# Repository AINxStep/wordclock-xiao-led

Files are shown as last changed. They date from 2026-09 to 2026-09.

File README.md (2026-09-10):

# Reloj de Palabras (WordClock) - Español Mexicano
### Hardware: Seeed Studio XIAO ESP32-C6 + Matriz 158 LEDs WS2812B





🌐 **Idioma / Language:** **Español** | [English](README.en.md)

<p align="center">
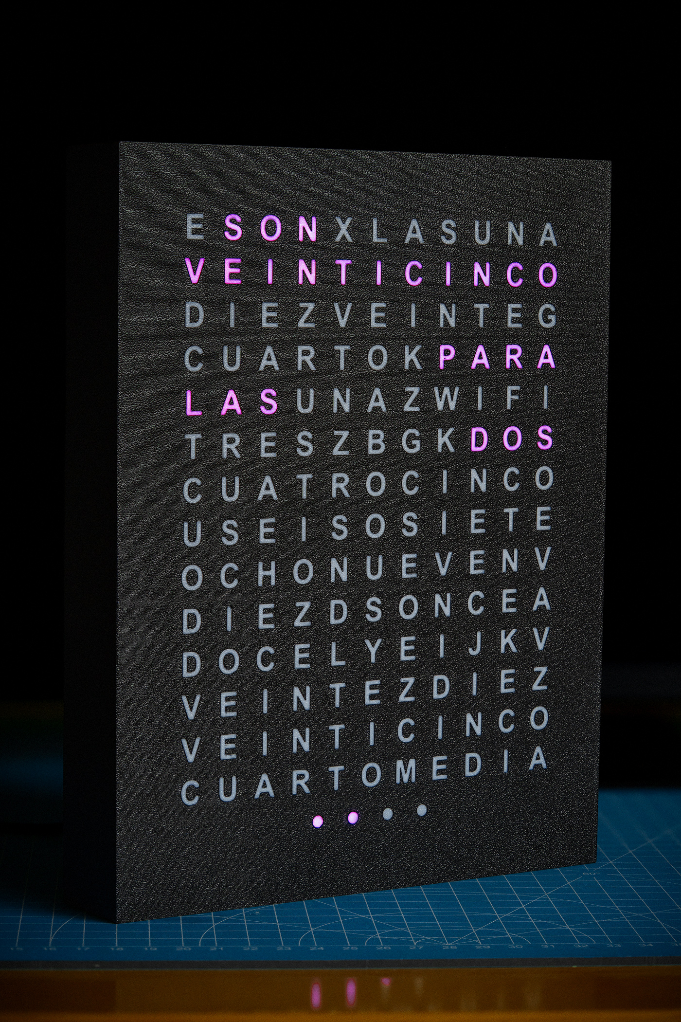
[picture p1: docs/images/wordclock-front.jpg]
Reloj de Palabras - WordClock Español Mexicano
  
  <br>
  <em>WordClock en funcionamiento físico mostrando las 1:37 («SON VEINTICINCO PARA LAS DOS» + 2 minutos)</em>
</p>

---

Proyecto completo de hardware, firmware, modelos 3D y simulador web para un reloj de palabras (*WordClock*) **regionalizado para el español de México** (particularmente el centro del país), con matriz de 158 LEDs direccionables WS2812B y sincronización WiFi / RTC.

---

## 🇲🇽 El Factor Diferenciador: Español Mexicano

La inmensa mayoría de los relojes de palabras en español existentes en internet fueron creados según la convención de España (castellano europeo), la cual utiliza la estructura de resta (*"Las tres menos cuarto"*, *"Las cuatro menos diez"*, *"Las seis menos veinte"*).

En **México**, la manera natural y cotidiana en que decimos la hora invierte la estructura a partir del minuto 35, expresando los minutos que faltan **PARA** la siguiente hora:

* ❌ **Enfoque europeo:** `SON LAS TRES MENOS CUARTO`
* 🇲🇽 **Enfoque mexicano (este WordClock):** `CUARTO PARA LAS TRES`, `DIEZ PARA LAS CUATRO`, `VEINTICINCO PARA LA UNA`

### Adaptación física de la matriz
Para soportar esta sintaxis mexicana de forma natural y visualmente coherente, la matriz de 11×14 se dividió estratégicamente en 3 secciones:

1. **Filas superiores (1 a 4) - Bloque "PARA":** Contienen los minutos preliminares (`VEINTICINCO`, `DIEZ`, `VEINTE`, `CUARTO`), la palabra clave `PARA`, y los artículos `LA` / `LAS` / `UNA` más el indicador de estado `WIFI`.
2. **Filas intermedias (5 a 10) - Bloque de Horas:** Mapean las doce horas (`UNA` a `DOCE`) en orden lógico y optimizado.
3. **Filas inferiores (11 a 13) - Bloque "Y":** Contienen la conjunción `Y` junto con los minutos para la primera mitad de la hora (`DIEZ`, `VEINTE`, `VEINTICINCO`, `CUARTO`, `MEDIA`).
4. **Fila 14 (Puntos de precisión):** 4 LEDs individuales (+1, +2, +3, +4) para lectura exacta minuto a minuto.

---

## Estructura del Repositorio

El repositorio está organizado en módulos independientes para facilitar la navegación y el mantenimiento:

```text
wordclock/
├── docs/                                  # Especificaciones técnicas, esquemas y recursos
│   ├── images/                            # Fotografías y renders del proyecto
│   │   ├── wordclock-front.jpg            # Vista frontal en funcionamiento
│   │   ├── wordclock-internals.jpg        # Ensamble interior y electrónica
│   │   └── wordclock-angle.jpg            # Despiece del ensamble 3D en CAD
│   ├── matrix-layout.txt                  # Mapeo físico detallado de los 158 LEDs (cableado progresivo)
│   └── matrix-grid.txt                    # Distribución de la cuadrícula de texto (11x14)
│
├── simulator/                             # Simulador Web interactivo
│   ├── index.html                         # Interfaz gráfica del simulador
│   ├── index.css                          # Estilos visuales y efectos de iluminación LED
│   └── app.js                             # Lógica de tiempo en español mexicano y portal WiFi
│
├── arduino/                               # Firmware para Arduino IDE
│   ├── wordclock/                         # Sketch principal
│   │   └── wordclock.ino                  # Firmware completo (ESP32-C6 + FastLED + RTC DS1307 + AP Portal)
│   ├── test_words/                        # Sketch de diagnóstico y pruebas
│   │   └── test_words.ino                 # Prueba secuencial de palabras e iluminación
│   └── reference/                         # Códigos de referencia y ejemplos base
│       └── wordclock-example.code.txt
│
├── 3d_models/                             # Archivos de impresión 3D (OpenSCAD, STL, 3MF)
│   ├── best_parameters.txt                # Parámetros recomendados de laminación (Bambu Studio)
│   ├── opcion_1_tapa_superpuesta/         # Opción 1: Tapa exterior superpuesta para marco estándar
│   └── opcion_2_tapa_incrustada_al_ras/   # Opción 2: Tapa incrustada al ras para marco optimizado
│
└── LICENSE                                # Licencia dual (MIT para software, CC BY-SA 4.0 para hardware/3D)
```

---

## Hardware y Lista de Materiales (BOM)

* **Placa Base / Driver**: [Seeed LED Driver Board](https://wiki.seeedstudio.com/led_driver_board/) (Alimentación única 12V DC, regulador interno, zócalo integrado para XIAO, puerto Grove I2C y salida directa para tira LED)
* **Microcontrolador**: [Seeed Studio XIAO ESP32-C6](https://wiki.seeedstudio.com/xiao_esp32c6_getting_started/) (montado directamente en el zócalo de la placa driver)
* **Módulo RTC**: [Grove - DS1307 RTC](https://wiki.seeedstudio.com/Grove-RTC/#pre-reading) (conectado con cable Grove nativo al puerto I2C de la placa driver)
* **Tira de LEDs**: WS2812B de 74 LEDs/m (158 LEDs en total: matriz 11×14 + 4 puntos de minutos)
* **Conector de Chasis**: [Puerto USB-C Hembra impermeable para panel (2 pines, 3A)](https://es.aliexpress.com/item/1005011950115260.html) con cable de extensión hacia la placa driver
* **Alimentación**: [Adaptador de Corriente Universal USB-C 24W (12V @ 2A)](https://es.aliexpress.com/item/1005007438665930.html)

<p align="center">
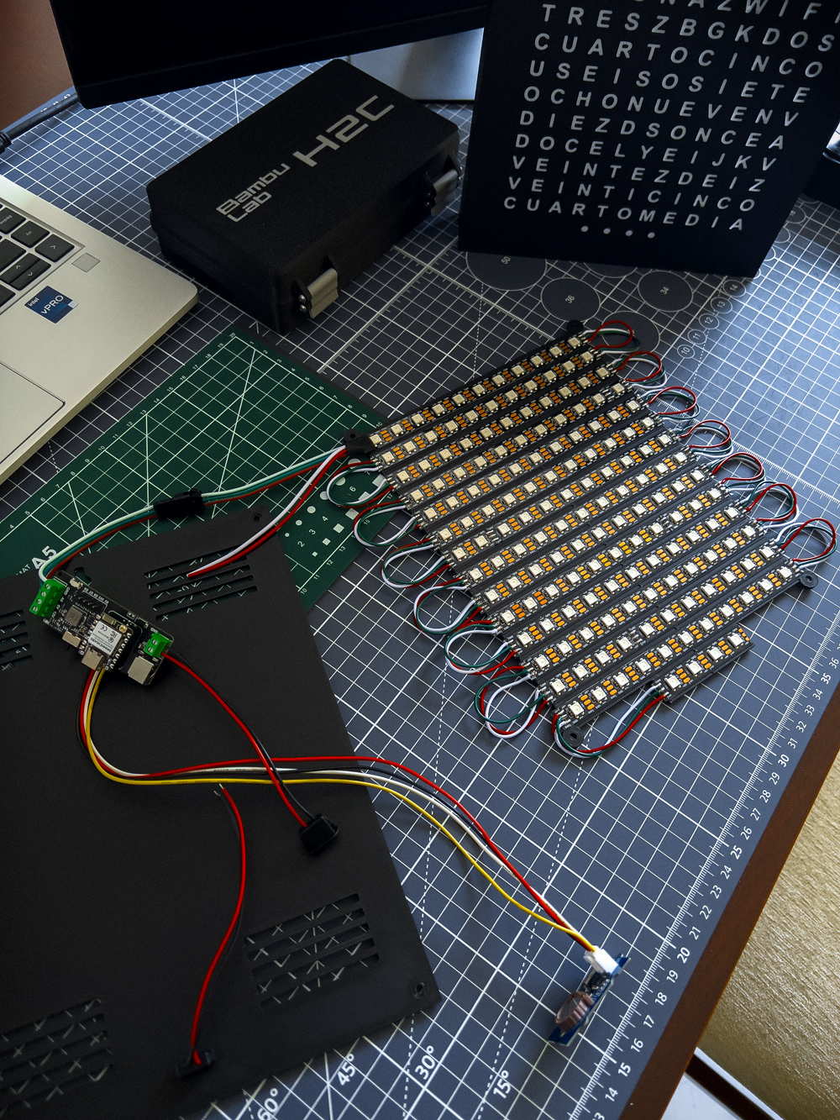
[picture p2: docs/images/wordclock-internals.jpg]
Ensamble interno y componentes de WordClock
  
  <br>
  <em>Componentes y cableado interno: Placa Seeed LED Driver con XIAO ESP32-C6, módulo Grove RTC (DS1307), placa posterior con ventilación y matriz de tiras LED WS2812B interconectadas</em>
</p>

### Diagrama de Conexiones

```mermaid
flowchart TD
    subgraph PWR["Alimentación Externa y Chasis"]
        V12["Adaptador USB-C 12V / 2A (24W)"]
        USBC_PORT["Puerto USB-C Hembra Impermeable (Panel Trasero)"]
    end

    subgraph DriverBoard["Seeed Studio LED Driver Board (Placa Base)"]
        DC_IN["Entrada de Alimentación: 12V DC"]
        REG["Regulación interna DC-DC (12V → 5V / 3.3V) + Level Shifter"]

        subgraph XiaoSocket["Zócalo XIAO"]
            XIAO["Seeed Studio XIAO ESP32-C6<br>(Montado directamente en zócalo)"]
        end

        subgraph GrovePort["Puerto Grove I2C"]
            GROVE_OUT["SCL / SDA / VCC / GND"]
        end

        subgraph LedOut["Conector de Salida para Tira LED"]
            OUT_GND["GND"]
            OUT_DAT["DATA (5V Level-Shifted)"]
            OUT_5V["+5V"]
            OUT_12V["+12V (No utilizado)"]
        end
    end

    subgraph RTC["Grove RTC (DS1307)"]
        RTC_PORT["Puerto Grove I2C<br>(SCL, SDA, VCC, GND)"]
    end

    subgraph Matriz["Matriz LEDs WS2812B (158 LEDs)"]
        LED_DIN["DIN (LED #0)"]
        LED_VCC["+5V"]
        LED_GND["GND"]
    end

    V12 --> USBC_PORT
    USBC_PORT --> DC_IN
    DC_IN --> REG
    REG --> XIAO
    REG --> GrovePort
    REG --> LedOut

    GrovePort <== Cable Grove (I2C + Energía) ==> RTC_PORT

    OUT_DAT --> LED_DIN
    OUT_5V --> LED_VCC
    OUT_GND --> LED_GND
```

### Tabla de Cableado

| Conector / Puerto | Pines / Terminales | Componente Conectado | Función / Descripción |
| :--- | :--- | :--- | :--- |
| **Panel Trasero (Chasis)** | `VBUS (12V)`, `GND` | [Puerto USB-C Hembra Impermeable](https://es.aliexpress.com/item/1005011950115260.html) | Entrada externa en el chasis para recibir alimentación mediante cable USB-C |
| **Entrada DC Driver** | `12V`, `GND` | [Adaptador USB-C 12V @ 2A](https://es.aliexpress.com/item/1005007438665930.html) | Fuente conmutada regulada de 24W que alimenta todo el sistema |
| **Zócalo XIAO** | Headers hembra | [XIAO ESP32-C6](https://wiki.seeedstudio.com/xiao_esp32c6_getting_started/) | Interconexión directa de energía, bus I2C y pin de señal `D0/GPIO 0` |
| **Puerto Grove I2C** | `SCL`, `SDA`, `VCC`, `GND` | [Grove RTC (DS1307)](https://wiki.seeedstudio.com/Grove-RTC/#pre-reading) | Conexión directa mediante cable Grove estándar (datos I2C + energía) |
| **Conector Salida LED**| `DATA`, `+5V`, `GND` | Matriz WS2812B (158 LEDs) | Salida regulada a 5V y señal digital para el primer LED (`DIN`) |

> [!TIP]
> **Alimentación del sistema**: El reloj requiere únicamente un adaptador externo de **12V @ 2A**. La placa Seeed LED Driver Board se encarga internamente de convertir y distribuir los voltajes requeridos: 3.3V para el microcontrolador XIAO, 5V para el módulo Grove RTC y 5V con suficiente corriente para alimentar los 158 LEDs WS2812B.

---

## Matriz de Letras (11×14 + 4 Puntos)

```text
Fila 0  (0-10):    E S O N X L A S U N A    (ES, SON, LA, LAS, UNA)
Fila 1  (11-21):   V E I N T I C I N C O    (Minutos para bloque PARA)
Fila 2  (22-32):   D I E Z V E I N T E G    (Minutos para bloque PARA)
Fila 3  (33-43):   C U A R T O K P A R A    (CUARTO, PARA)
Fila 4  (44-54):   L A S U N A Z W I F I    (LA, LAS, UNA para bloque PARA + WIFI)
Fila 5  (55-65):   T R E S Z B G K D O S    (Horas: TRES, DOS)
Fila 6  (66-76):   C U A T R O C I N C O    (Horas: CUATRO, CINCO)
Fila 7  (77-87):   U S E I S O S I E T E    (Horas: SEIS, SIETE)
Fila 8  (88-98):   O C H O N U E V E N V    (Horas: OCHO, NUEVE)
Fila 9  (99-109):  D I E Z D S O N C E A    (Horas: DIEZ, ONCE)
Fila 10 (110-120): D O C E L Y E I J K V    (Horas: DOCE, Conjunción Y)
Fila 11 (121-131): V E I N T E Z D I E Z    (Minutos para bloque Y)
Fila 12 (132-142): V E I N T I C I N C O    (Minutos para bloque Y)
Fila 13 (143-153): C U A R T O M E D I A    (Minutos para bloque Y)
Fila 14 (154-157): Puntos de minutos (+1, +2, +3, +4)
```

* **Bloque "Y"** (minutos 00 a 34): *Ej. "SON LAS ONCE Y VEINTE"*, *"ES LA UNA Y DIEZ"*
* **Bloque "PARA"** (minutos 35 a 59): *Ej. "VEINTICINCO PARA LAS DOCE"*, *"CUARTO PARA LA UNA"*
* **Puntos de minutos (+1 a +4)**: Ajuste exacto de minutos individuales.

---

## Cómo Usar

### 1. Simulador Web
* **🌐 Probar en línea (sin descargas)**: Accede a la demo en vivo directamente en [ainxstep.github.io/wordclock-xiao-led](https://ainxstep.github.io/wordclock-xiao-led/).
* **💻 Ejecución local**: Abre directamente `simulator/index.html` en cualquier navegador web moderno para verificar la lógica de iluminación en español mexicano, ajustar la hora manualmente con el slider o sincronizarla en tiempo real.

### 2. Firmware (Arduino IDE)
1. Instala la placa **ESP32 by Espressif Systems** en el Gestor de Placas de Arduino IDE.
2. Instala las librerías necesarias: `FastLED` y `RTClib` (Adafruit).
3. Abre el sketch `arduino/wordclock/wordclock.ino`.
4. Selecciona la placa **Seeed Studio XIAO ESP32C6** y el puerto correspondiente.
5. Compila y carga el código.

### 3. Impresión 3D y Ensamble

<p align="center">
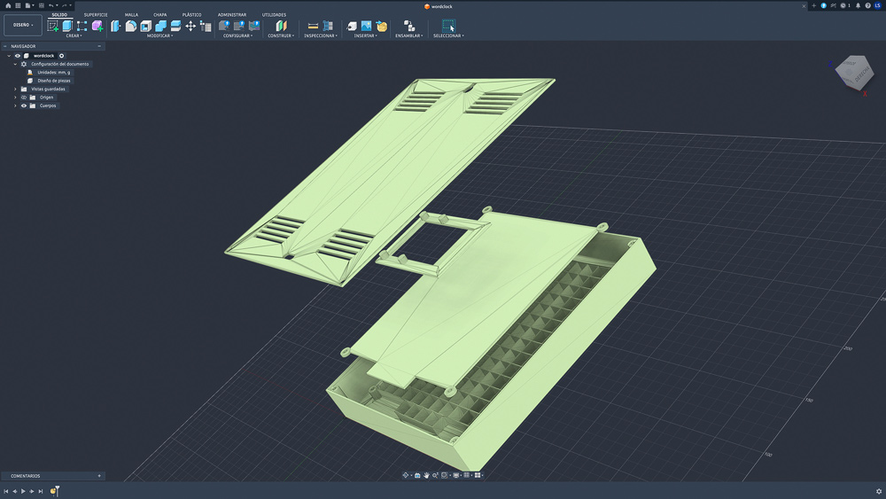
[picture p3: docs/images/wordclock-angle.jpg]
Despiece y ensamble 3D de WordClock
  
  <br>
  <em>Despiece del ensamble 3D: Marco frontal con rejilla de aislamiento óptico, placa porta-LEDs, soporte de electrónica y tapa trasera ventilada</em>
</p>

Dentro de `3d_models/` se encuentran los modelos paramétricos en OpenSCAD y los archivos `.stl` / `.3mf` listos para laminar:
* **Marco principal (`wordclock_main_frame`)**: Frontal con celdas individuales para cada letra y punto de minuto, diseñadas para aislar completamente la luz de cada LED (*anti-light-bleed*).
* **Placa de LEDs (`wordclock_led_plate`)**: Base con ranuras y marcas para el pegado y alineación milimétrica de las tiras WS2812B.
* **Soporte de electrónica (`wordclock_electronics_mount`)**: Base adaptada para fijar con tornillos la placa Seeed LED Driver y el módulo RTC.
* **Tapa trasera (`wordclock_back_lid`)**: Disponible en dos opciones: **Opción 1** (tapa superpuesta estándar) y **Opción 2** (tapa incrustada al ras), ambas con ranuras para ventilación pasiva.

Consulta `3d_models/best_parameters.txt` para los ajustes de capa, ancho de línea y patrones de relleno recomendados en Bambu Studio.

> [!TIP]
> **Proyecto listo para Bambu Studio**: Si utilizas una impresora Bambu Lab (o Bambu Studio / OrcaSlicer), puedes abrir directamente el archivo de proyecto preconfigurado [`3d_models/opcion_2_tapa_incrustada_al_ras/wordclock.3mf`](3d_models/opcion_2_tapa_incrustada_al_ras/wordclock.3mf). Contiene las bandejas organizadas, orientaciones óptimas de piezas, asignación de filamentos y parámetros de laminación listos para imprimir con un clic.

### 4. Configuración Inicial y Portal WiFi

Al conectar el reloj a la alimentación USB, la palabra **WIFI** pulsa suavemente durante los primeros **60 segundos**, indicando que la red de configuración está activa y lista para recibir conexiones.

1. **Conéctate a la red**: Desde tu teléfono o computadora, conéctate a la red WiFi **`WORDCLOCK-SETUP`** (red abierta, sin contraseña).
2. **Accede al portal**: Se abrirá automáticamente la ventana del portal cautivo. Si no aparece sola, entra desde el navegador a `http://192.168.4.1`.
3. **Ajusta tus preferencias**:
   * **Sincronizar hora**: Presiona el botón para transferir al instante la hora y fecha exacta de tu teléfono al chip RTC (Grove DS1307).
   * **Color y brillo**: Elige el color de las palabras y gradúa el brillo diurno y nocturno (optimizado con corrección Gamma 2.2).
   * **Horario nocturno**: Define el intervalo de horas para el modo tenue (ej. 22:00 a 06:00).
4. **Guarda**: Presiona **"Guardar Configuración"**. Los ajustes se aplican de inmediato y se almacenan en la memoria permanente (NVS) del ESP32.

> [!NOTE]
> **Modo normal y reconfiguración**: Si pasan 60 segundos sin conexión o en cuanto te desconectas del portal, la antena WiFi y la palabra **WIFI** se apagan por completo para no emitir radiofrecuencia. Para volver a abrir el portal de configuración en el futuro, simplemente **desconecta y vuelve a conectar el cable de alimentación USB**.

---

## Licencia

Este proyecto cuenta con un esquema de licenciamiento dual:
* **Software y Firmware (`arduino/`, `simulator/`)**: Licencia [MIT](LICENSE).
* **Modelos 3D, Hardware y Documentación (`3d_models/`, `docs/`)**: Licencia [Creative Commons Atribución-CompartirIgual 4.0 Internacional (CC BY-SA 4.0)](LICENSE).

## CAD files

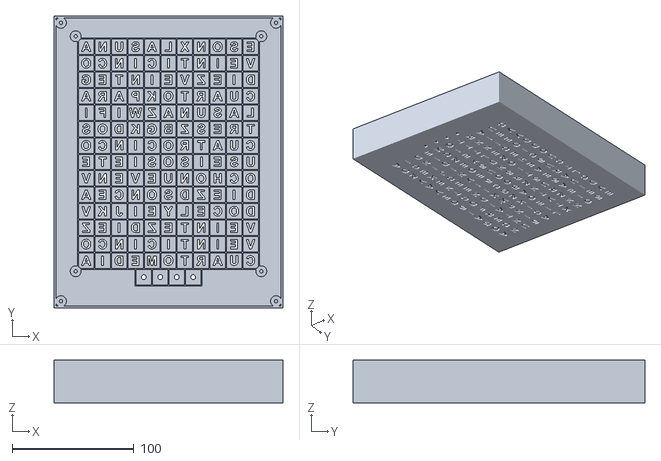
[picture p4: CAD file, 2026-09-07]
3d_models/opcion_2_tapa_incrustada_al_ras/wordclock_main_frame.stl
188.0 x 240.0 x 35.0

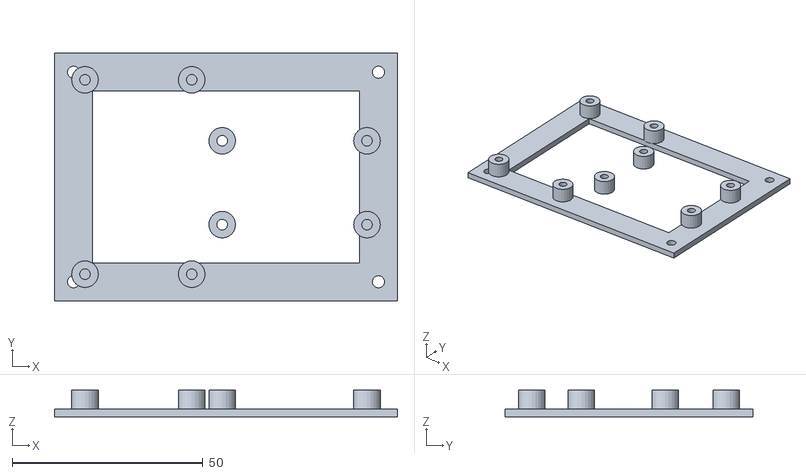
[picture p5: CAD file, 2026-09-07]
3d_models/opcion_1_tapa_superpuesta/wordclock_electronics_mount.stl
90.0 x 65.0 x 7.00

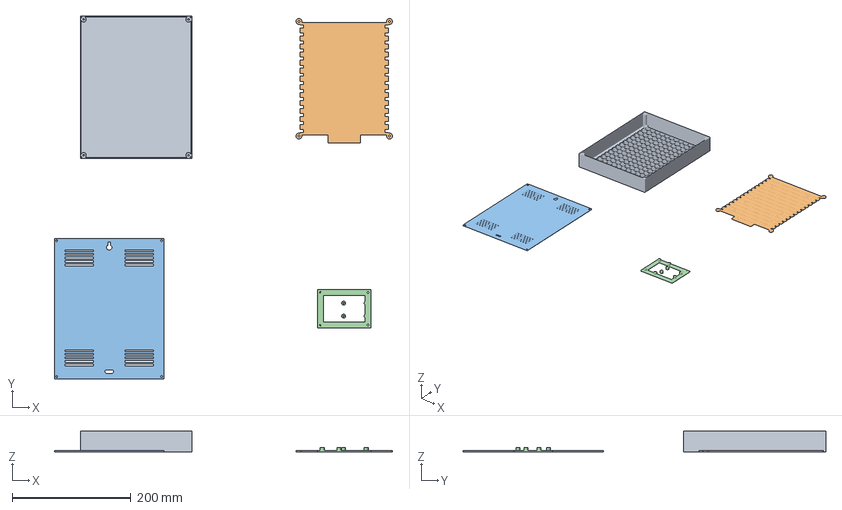
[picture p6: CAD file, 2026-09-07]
3d_models/opcion_2_tapa_incrustada_al_ras/wordclock.3mf
569.5 x 611.3 x 35.0 mm
wordclock_letters_infill
wordclock_led_plate.stl
wordclock_back_lid.stl
wordclock_electronics_mount.stl

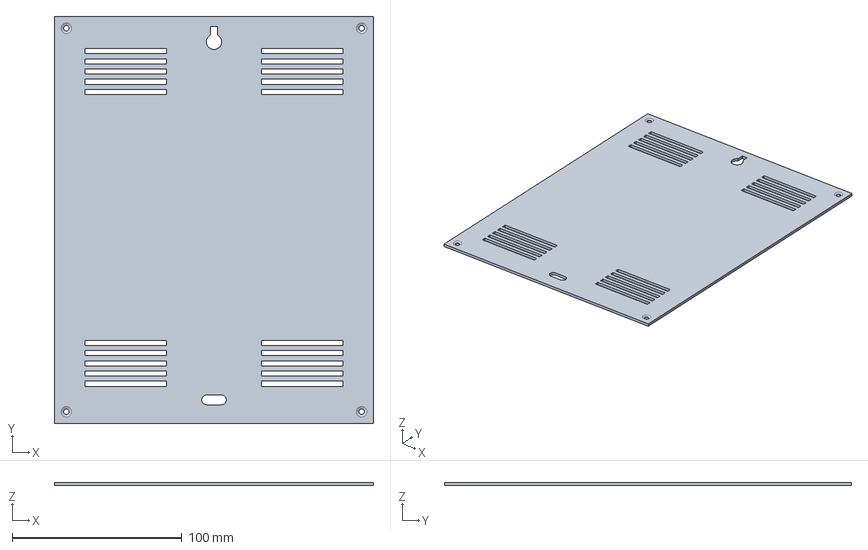
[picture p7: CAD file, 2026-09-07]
3d_models/opcion_1_tapa_superpuesta/wordclock_back_lid.3mf
188.0 x 240.0 x 2.00 mm

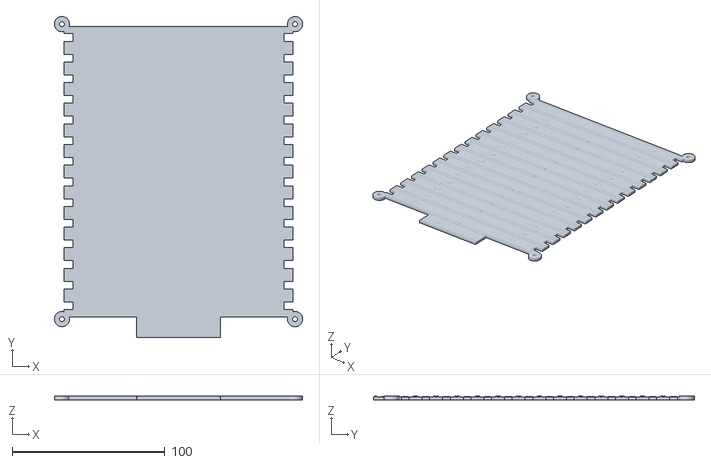
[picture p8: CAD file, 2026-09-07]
3d_models/opcion_2_tapa_incrustada_al_ras/wordclock_led_plate.stl
162.6 x 210.2 x 2.40

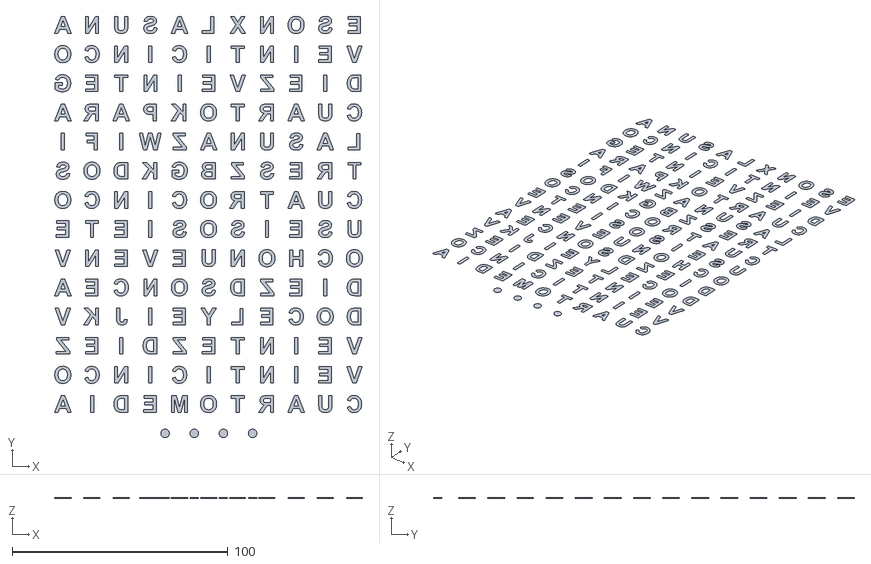
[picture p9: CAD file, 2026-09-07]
3d_models/opcion_1_tapa_superpuesta/wordclock_letters_infill.stl
142.7 x 195.3 x 0.4

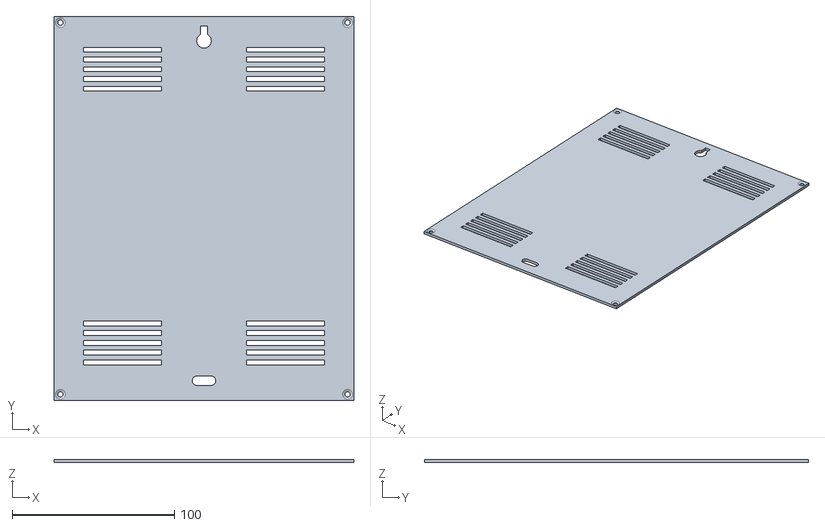
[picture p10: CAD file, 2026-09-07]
3d_models/opcion_2_tapa_incrustada_al_ras/wordclock_back_lid.stl
184.4 x 236.4 x 2.00

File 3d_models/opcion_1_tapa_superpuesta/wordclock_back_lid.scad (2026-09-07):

// ==============================================================================
// WORDCLOCK ESP32 - OPCION 1: TAPA TRASERA SUPERPUESTA (PARA MARCO YA IMPRESO)
// PIEZA 3: TAPA SUPERPUESTA DE 188.0 x 240.0 mm
// Offset de tornillos: 7.0 mm (Coincide EXACTAMENTE con la impresión física realizada)
// Avellanado simétrico (doble cara) para que la cabeza del tornillo encaje sin importar el lado
// ==============================================================================

box_w       = 188.0;   // Ancho exterior completo (188 mm)
box_h       = 240.0;   // Alto exterior completo (240 mm)
wall_thick  = 3.0;     // Pared de 3.0 mm coincidente con el marco impreso
lid_thick   = 2.0;     // Grosor de la tapa

// Centro de tornillos a 7.0 mm desde las esquinas exteriores
screw_off   = wall_thick + 4.0; // 3.0 + 4.0 = 7.0 mm

module double_countersunk_hole(h = 2.0) {
    union() {
        // Pasante central M3
        translate([0, 0, -0.1]) cylinder(r = 1.6, h = h + 0.2, $fn = 32);
        
        // Avellanado Cara A (Cono de 1.6 mm a 3.3 mm en los primeros 0.9 mm)
        translate([0, 0, -0.1]) cylinder(r1 = 3.3, r2 = 1.6, h = 0.9, $fn = 32);
        
        // Avellanado Cara B (Cono de 1.6 mm a 3.3 mm en los últimos 0.9 mm)
        translate([0, 0, h - 0.8]) cylinder(r1 = 1.6, r2 = 3.3, h = 0.9, $fn = 32);
    }
}

module wordclock_back_lid() {
    difference() {
        // 1. Placa Base de la Tapa (188.0 x 240.0 x 2.0 mm)
        cube([box_w, box_h, lid_thick]);

        // 2. Orificios M3 con Avellanado Doble Cara (Offset exacto 7.0 mm)
        translate([screw_off, screw_off, 0])                 double_countersunk_hole(lid_thick);
        translate([box_w - screw_off, screw_off, 0])         double_countersunk_hole(lid_thick);
        translate([screw_off, box_h - screw_off, 0])         double_countersunk_hole(lid_thick);
        translate([box_w - screw_off, box_h - screw_off, 0]) double_countersunk_hole(lid_thick);

        // 3. Ranuras de Ventilación Superior
        for (i = [0 : 4]) {
            y_slot = box_h - 22 - (i * 6);
            translate([18, y_slot, -0.1])         cube([48, 3.0, lid_thick + 0.2]);
            translate([box_w - 66, y_slot, -0.1]) cube([48, 3.0, lid_thick + 0.2]);
        }

        // 4. Ranuras de Ventilación Inferior
        for (i = [0 : 4]) {
            y_slot = 22 + (i * 6);
            translate([18, y_slot, -0.1])         cube([48, 3.0, lid_thick + 0.2]);
            translate([box_w - 66, y_slot, -0.1]) cube([48, 3.0, lid_thick + 0.2]);
        }

        // 5. RANURA USB-C OBLONGA / PANELSOCKET (14.5 x 5.8 mm con r = 2.9 mm)
        translate([box_w / 2, 14.0, -0.1]) {
            hull() {
                translate([-4.35, 0, 0]) cylinder(r = 2.9, h = lid_thick + 0.2, $fn = 32);
                translate([ 4.35, 0, 0]) cylinder(r = 2.9, h = lid_thick + 0.2, $fn = 32);
            }
        }

        // 6. Muesca de cerradura (Keyhole) para colgar en pared
        translate([box_w / 2, box_h - 15, -0.1]) {
            union() {
                cylinder(r = 4.5, h = lid_thick + 0.2, $fn = 24);
                translate([-2.2, 0, 0]) cube([4.4, 9.0, lid_thick + 0.2]);
            }
        }
    }
}

wordclock_back_lid();

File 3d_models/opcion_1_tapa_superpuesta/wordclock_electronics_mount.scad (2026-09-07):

// ==============================================================================
// WORDCLOCK ESP32 - OPCION 1: SOPORTE DE ELECTRONICA INDEPENDIENTE
// PIEZA 4: BANDEJA DE MONTAJE PARA ESP32 + MODULO RTC DS1307
// ==============================================================================

tray_w     = 90.0;
tray_h     = 65.0;
tray_thick = 2.0;
standoff_h = 5.0;

module m3_boss(h = 5.0) {
    difference() {
        cylinder(r = 3.5, h = h, $fn = 24);
        translate([0, 0, -0.1]) cylinder(r = 1.4, h = h + 0.2, $fn = 24);
    }
}

module wordclock_electronics_mount() {
    union() {
        difference() {
            cube([tray_w, tray_h, tray_thick]);

            translate([10, 10, -0.1]) {
                cube([tray_w - 20, tray_h - 20, tray_thick + 0.2]);
            }

            translate([5, 5, -0.1])           cylinder(r = 1.6, h = tray_thick + 0.2, $fn = 24);
            translate([tray_w - 5, 5, -0.1])   cylinder(r = 1.6, h = tray_thick + 0.2, $fn = 24);
            translate([5, tray_h - 5, -0.1])  cylinder(r = 1.6, h = tray_thick + 0.2, $fn = 24);
            translate([tray_w - 5, tray_h - 5, -0.1]) cylinder(r = 1.6, h = tray_thick + 0.2, $fn = 24);
        }

        esp32_x = 8;
        esp32_y = 7;
        translate([esp32_x, esp32_y, tray_thick]) {
            m3_boss(standoff_h);
            translate([28, 0, 0])  m3_boss(standoff_h);
            translate([0, 51, 0])  m3_boss(standoff_h);
            translate([28, 51, 0]) m3_boss(standoff_h);
        }

        rtc_x = 44;
        rtc_y = 20;
        translate([rtc_x, rtc_y, tray_thick]) {
            m3_boss(standoff_h);
            translate([38, 0, 0])  m3_boss(standoff_h);
            translate([0, 22, 0])  m3_boss(standoff_h);
            translate([38, 22, 0]) m3_boss(standoff_h);
        }
    }
}

wordclock_electronics_mount();

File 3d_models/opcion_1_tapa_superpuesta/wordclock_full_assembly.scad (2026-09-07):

// ==============================================================================
// WORDCLOCK ESP32 - OPCION 1: VISTA GENERAL DE ENSAMBLAJE & EXPLOSIONADA (EXPLODED VIEW)
// Modelo concentrado para auditoría 3D de ajuste entre piezas (Marco 3.0 mm + Tapa 188x240 mm)
// ==============================================================================

/* [Controles de Vista e Inspección / View Controls] */
// Desplazamiento de explosión en mm (0 = 100% Ensamblado Real, >0 = Vista Despiezada/Explosionada)
explode_distance = 0; // [0:1:120]

// Modo Transparencia para inspeccionar interferencias internas y alineación de tornillos
transparent_view = 0; // [0:Sólido, 1:Transparente]

// Visibilidad de Piezas Individuales
show_main_frame       = 1; // [0:Ocultar, 1:Mostrar]
show_led_plate        = 1; // [0:Ocultar, 1:Mostrar]
show_electronics_mount= 1; // [0:Ocultar, 1:Mostrar]
show_back_lid         = 1; // [0:Ocultar, 1:Mostrar]

// Incluir definidores de módulos de las 4 piezas
include <wordclock_main_frame.scad>
include <wordclock_back_lid.scad>

// --- Definición abreviada de la Placa de LEDs (Pieza 2) ---
module led_plate_component() {
    grid_w      = (11 - 1) * 13.5135;
    grid_h      = (14 - 1) * 13.5135;
    margin_x    = (188.0 - grid_w) / 2;
    margin_top  = (240.0 - grid_h - 13.5135) / 2;
    dots_y      = 240.0 - margin_top - (14 * 13.5135);
    
    plate_left  = margin_x - (13.5135 / 2) - 0.5;
    plate_right = margin_x + grid_w + (13.5135 / 2) + 0.5;
    plate_top   = 240.0 - margin_top + (13.5135 / 2) + 0.5;
    plate_bot   = 240.0 - margin_top - grid_h - (13.5135 / 2) - 0.5;
    plate_w     = plate_right - plate_left;
    plate_h     = plate_top - plate_bot;
    
    baffle_left  = margin_x - (13.5135 / 2) - 2.0;
    baffle_right = margin_x + grid_w + (13.5135 / 2) + 2.0;
    baffle_top   = 240.0 - margin_top + (13.5135 / 2) + 2.0;
    baffle_bot   = 240.0 - margin_top - grid_h - (13.5135 / 2) - 2.0;
    
    difference() {
        union() {
            translate([plate_left, plate_bot, 0]) cube([plate_w, plate_h, 2.0]);
            dots_plate_w = (4 * 13.5135) + 0.8;
            dots_plate_x = margin_x + (3.0 * 13.5135) - 0.4;
            dots_plate_y = dots_y - (13.5135 / 2) - 0.5;
            dots_plate_h = (plate_bot - dots_plate_y) + 1.0;
            translate([dots_plate_x, dots_plate_y, 0]) cube([dots_plate_w, dots_plate_h, 2.0]);
            
            // 4 Orejas de fijación
            translate([baffle_left, baffle_top, 0])   cylinder(r = 5.0, h = 2.4, $fn = 32);
            translate([baffle_right, baffle_top, 0])  cylinder(r = 5.0, h = 2.4, $fn = 32);
            translate([baffle_left, baffle_bot, 0])   cylinder(r = 5.0, h = 2.4, $fn = 32);
            translate([baffle_right, baffle_bot, 0])  cylinder(r = 5.0, h = 2.4, $fn = 32);
        }
        // Pasantes M3 en las 4 orejas
        translate([baffle_left, baffle_top, -0.1])   cylinder(r = 1.6, h = 3.0, $fn = 32);
        translate([baffle_right, baffle_top, -0.1])  cylinder(r = 1.6, h = 3.0, $fn = 32);
        translate([baffle_left, baffle_bot, -0.1])   cylinder(r = 1.6, h = 3.0, $fn = 32);
        translate([baffle_right, baffle_bot, -0.1])  cylinder(r = 1.6, h = 3.0, $fn = 32);
    }
}

// --- Definición abreviada del Soporte de Electrónica (Pieza 4) ---
module electronics_mount_component() {
    difference() {
        cube([90.0, 65.0, 2.0]);
        translate([10, 10, -0.1]) cube([70.0, 45.0, 2.2]);
        translate([5, 5, -0.1])           cylinder(r = 1.6, h = 2.2, $fn = 24);
        translate([85, 5, -0.1])          cylinder(r = 1.6, h = 2.2, $fn = 24);
        translate([5, 60, -0.1])          cylinder(r = 1.6, h = 2.2, $fn = 24);
        translate([85, 60, -0.1])         cylinder(r = 1.6, h = 2.2, $fn = 24);
    }
    // Torretas M3 para ESP32
    translate([8, 7, 2.0]) {
        cylinder(r = 3.5, h = 5.0, $fn = 24);
        translate([28, 0, 0])  cylinder(r = 3.5, h = 5.0, $fn = 24);
        translate([0, 51, 0])  cylinder(r = 3.5, h = 5.0, $fn = 24);
        translate([28, 51, 0]) cylinder(r = 3.5, h = 5.0, $fn = 24);
    }
}

// --- RENDERING DEL ENSAMBLAJE TOTAL ---
alpha_val = (transparent_view == 1) ? 0.45 : 1.0;

module full_wordclock_assembly() {
    // 1. Pieza 1: Marco Principal (Z = 0)
    if (show_main_frame == 1) {
        color([0.22, 0.22, 0.22, alpha_val]) {
            wordclock_main_frame();
        }
    }

    // 2. Pieza 2: Placa Porta-LEDs (Apoyada a Z = face_thick + baffle_h = 14.4 mm)
    if (show_led_plate == 1) {
        translate([0, 0, 14.4 + (explode_distance * 0.5)]) {
            color([0.9, 0.9, 0.9, alpha_val]) {
                led_plate_component();
            }
        }
    }

    // 3. Pieza 4: Soporte de Electrónica (Centrado a Z = 22.0 mm)
    if (show_electronics_mount == 1) {
        translate([49.0, 87.5, 20.0 + (explode_distance * 1.1)]) {
            color([0.1, 0.6, 0.8, alpha_val]) {
                electronics_mount_component();
            }
        }
    }

    // 4. Pieza 3: Tapa Trasera (Montada a Z = 35.0 mm por fuera)
    if (show_back_lid == 1) {
        translate([0, 0, 35.0 + (explode_distance * 1.8)]) {
            color([0.85, 0.55, 0.2, alpha_val]) {
                wordclock_back_lid();
            }
        }
    }
}

// Renderizar ensamblaje completo con la distancia de explosión seleccionada
full_wordclock_assembly();

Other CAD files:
3d_models/opcion_2_tapa_incrustada_al_ras/wordclock_letters_infill.stl
3d_models/opcion_1_tapa_superpuesta/wordclock_led_plate.stl
3d_models/opcion_2_tapa_incrustada_al_ras/wordclock_electronics_mount.stl
3d_models/opcion_1_tapa_superpuesta/wordclock_led_plate.scad
3d_models/opcion_1_tapa_superpuesta/wordclock_back_lid.stl
3d_models/opcion_1_tapa_superpuesta/wordclock_letters_infill.scad
3d_models/opcion_1_tapa_superpuesta/wordclock_main_frame.scad
3d_models/opcion_2_tapa_incrustada_al_ras/wordclock_back_lid.scad
3d_models/opcion_2_tapa_incrustada_al_ras/wordclock_electronics_mount.scad
3d_models/opcion_2_tapa_incrustada_al_ras/wordclock_full_assembly.scad
3d_models/opcion_2_tapa_incrustada_al_ras/wordclock_led_plate.scad
3d_models/opcion_2_tapa_incrustada_al_ras/wordclock_letters_infill.scad
3d_models/opcion_2_tapa_incrustada_al_ras/wordclock_main_frame.scad

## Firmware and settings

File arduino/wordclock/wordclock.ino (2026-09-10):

/*
  Reloj de Palabras (WordClock Seeed Studio XIAO ESP32-C6)
  Hardware: Microcontrolador Seeed Studio XIAO ESP32-C6 + Seeed LED Driver Board + Grove RTC (DS1307)
  Matriz: 11x14 + 4 puntos de minutos (158 LEDs totales, WS2812B 74 LEDs/m)
  Pin de datos LED: D0 / A0 (GPIO 0) mediante Seeed LED Driver Board (Level Shifter 3.3V -> 5V)
  Bus I2C RTC: Puerto Grove I2C nativo (SDA/SCL a 100 kHz para módulo Grove DS1307)
  LED Integrado XIAO: GPIO 15 (Parpadeo durante modo WiFi AP activo)
  Indicador WiFi: índices 51-54 ("WIFI" en Fila 4)
  Configuración: Captive Portal WebServer idéntico al simulador en AP "WORDCLOCK-SETUP"
*/

#include <FastLED.h>
#include <Wire.h>
#include <RTClib.h>

#include <WiFi.h>
#include <WebServer.h>
#include <DNSServer.h>
#include <Preferences.h>
#include <time.h>

/* ========== Configuración Hardware Seeed Studio XIAO ESP32-C6 ========== */
#define DATA_PIN 0            // Pin D0 (GPIO 0) en XIAO ESP32-C6 (Entrada al Level Shifter del LED Driver Board)
#define LED_PIN_BUILTIN 15    // Pin LED Integrado en XIAO ESP32-C6 (Lógica Invertida: LOW = ON, HIGH = OFF)
#define NUM_LEDS 158

// Velocidad I2C Estándar para DS1307 (100 kHz)
#define I2C_SPEED_DS1307 100000UL

// Instancia del RTC Grove basado en chip DS1307
RTC_DS1307 rtc;

CRGB leds[NUM_LEDS];
CRGB targetLeds[NUM_LEDS];

WebServer server(80);
DNSServer dnsServer;
Preferences prefs;

const byte DNS_PORT = 53;

/* ========== Valores por Defecto ========== */
const uint8_t DEFAULT_DAY_BRI_PERCENT = 70;
const uint8_t DEFAULT_NIGHT_BRI_PERCENT = 20;
const uint8_t DEFAULT_NIGHT_START = 22;
const uint8_t DEFAULT_NIGHT_END = 6;
const CRGB DEFAULT_COLOR = CRGB(255, 140, 0); // Ámbar por defecto (#ff8c00)

/* ========== Configuración en Tiempo de Ejecución ========== */
uint8_t dayBrightPercent = DEFAULT_DAY_BRI_PERCENT;
uint8_t nightBrightPercent = DEFAULT_NIGHT_BRI_PERCENT;
uint8_t nightStartHour = DEFAULT_NIGHT_START;
uint8_t nightEndHour = DEFAULT_NIGHT_END;
CRGB WORD_COLOR = DEFAULT_COLOR;

/* Claves para Preferences (memoria no volátil) */
const char *P_NS = "nightStart";
const char *P_NE = "nightEnd";
const char *P_DB = "dayB";
const char *P_NB = "nightB";
const char *P_R = "rc";
const char *P_G = "gc";
const char *P_B = "bc";

/* ========== Corrección Gamma 2.2 y Modelado Perceptual Humano ========== */
// Mapea porcentajes/valores lineales (0-255) a emisión óptica percibida como lineal (Ley de Stevens)
const uint8_t PROGMEM GAMMA8[256] = {
    0,   1,   1,   1,   1,   1,   1,   1,   1,   1,   1,   1,   1,   1,   1,   1,
    1,   1,   1,   1,   1,   1,   1,   1,   1,   2,   2,   2,   2,   2,   2,   2,
    3,   3,   3,   3,   3,   4,   4,   4,   4,   5,   5,   5,   5,   6,   6,   6,
    6,   7,   7,   7,   8,   8,   8,   9,   9,   9,  10,  10,  11,  11,  11,  12,
   12,  13,  13,  13,  14,  14,  15,  15,  16,  16,  17,  17,  18,  18,  19,  19,
   20,  20,  21,  22,  22,  23,  23,  24,  25,  25,  26,  26,  27,  28,  28,  29,
   30,  30,  31,  32,  33,  33,  34,  35,  35,  36,  37,  38,  39,  39,  40,  41,
   42,  43,  43,  44,  45,  46,  47,  48,  49,  49,  50,  51,  52,  53,  54,  55,
   56,  57,  58,  59,  60,  61,  62,  63,  64,  65,  66,  67,  68,  69,  70,  71,
   73,  74,  75,  76,  77,  78,  79,  81,  82,  83,  84,  85,  87,  88,  89,  90,
   91,  93,  94,  95,  97,  98,  99, 100, 102, 103, 105, 106, 107, 109, 110, 111,
  113, 114, 116, 117, 119, 120, 121, 123, 124, 126, 127, 129, 130, 132, 133, 135,
  137, 138, 140, 141, 143, 145, 146, 148, 149, 151, 153, 154, 156, 158, 159, 161,
  163, 165, 166, 168, 170, 172, 173, 175, 177, 179, 181, 182, 184, 186, 188, 190,
  192, 194, 196, 197, 199, 201, 203, 205, 207, 209, 211, 213, 215, 217, 219, 221,
  223, 225, 227, 229, 231, 234, 236, 238, 240, 242, 244, 246, 248, 251, 253, 255
};

// Conversión perceptual de porcentaje de brillo (0-100%) a escala PWM con corrección Gamma
inline uint8_t perceptualBrightness(uint8_t percent) {
  if (percent == 0) return 0;
  if (percent > 100) percent = 100;
  uint8_t raw = map(percent, 0, 100, 0, 255);
  return pgm_read_byte(&GAMMA8[raw]);
}

// Suavizado sigmoide cuadrático (S-Curve) para transiciones fluidas de entrada y salida
inline uint8_t ease8InOut(uint8_t i) {
  if (i < 128) {
    return ((uint16_t)i * i) >> 7;
  } else {
    uint8_t j = 255 - i;
    return 255 - (((uint16_t)j * j) >> 7);
  }
}

/* ========== Estado de Configuración WiFi / Modo AP ========== */
bool apActive = false;
bool clientConnected = false;
unsigned long apStartTime = 0;

/* LED parpadeo integrado */
unsigned long lastBuiltinBlink = 0;
bool builtinLedState = false;

/* Variable global de seguimiento de minutos */
uint8_t lastMinute = 255;

/* Índices LED de estado para la palabra "WIFI" (final de la Fila 4: 51, 52, 53, 54) */
const uint8_t WIFI_LEDS[4] = { 51, 52, 53, 54 };

/* ========== Estado de Transición No Bloqueante entre Palabras ========== */
CRGB previousLeds[NUM_LEDS];
bool inTransition = false;
unsigned long transitionStartTime = 0;
const unsigned long TRANSITION_DURATION_MS = 800; // 800 ms de fundido cruzado perceptual suave

/* ========== DEPURACIÓN ========== */
#define DEBUG_SERIAL 1   // Cambiar a 0 para deshabilitar mensajes por el puerto serial
String debugWords = "";  // Reconstruido en cada llamada a buildTimeTarget()

inline void logW(const char *name) {
#if DEBUG_SERIAL
  debugWords += name;
  debugWords += " ";
#endif
}

/* ========== Mapeo de Palabras (Matriz 11x14) ========== */
// Verbos / Artículos / Hora "una" (Fila 0)
const uint8_t ES[] = {0, 1};
const uint8_t SON[] = {1, 2, 3};
const uint8_t LA[] = {5, 6};
const uint8_t LAS[] = {5, 6, 7};
const uint8_t UNA[] = {8, 9, 10};

// Minutos para bloque "PARA" (Filas 1, 2, 3 - Zig-zag serpentina)
const uint8_t VEINTICINCO_PARA[] = {21, 20, 19, 18, 17, 16, 15, 14, 13, 12, 11};
const uint8_t CINCO_PARA[] = {15, 14, 13, 12, 11};
const uint8_t DIEZ_PARA[] = {22, 23, 24, 25};
const uint8_t VEINTE_PARA[] = {26, 27, 28, 29, 30, 31};
const uint8_t CUARTO_PARA[] = {43, 42, 41, 40, 39, 38};
const uint8_t PARA[] = {36, 35, 34, 33};

// Artículos para bloque "PARA" (Fila 4 - Par L->R)
const uint8_t LA_PARA[] = {44, 45};
const uint8_t LAS_PARA[] = {44, 45, 46};
const uint8_t UNA_PARA[] = {47, 48, 49};

// Horas (Filas 5 a 10)
const uint8_t TRES[] = {65, 64, 63, 62};
const uint8_t DOS[] = {57, 56, 55};
const uint8_t CUATRO[] = {66, 67, 68, 69, 70, 71};
const uint8_t CINCO_H[] = {72, 73, 74, 75, 76};
const uint8_t SEIS[] = {86, 85, 84, 83};
const uint8_t SIETE[] = {81, 80, 79, 78, 77};
const uint8_t OCHO[] = {88, 89, 90, 91};
const uint8_t NUEVE[] = {92, 93, 94, 95, 96};
const uint8_t DIEZ_H[] = {109, 108, 107, 106};
const uint8_t ONCE[] = {103, 102, 101, 100};
const uint8_t DOCE[] = {110, 111, 112, 113};

// Conjunción "Y" (Fila 10 - Par L->R)
const uint8_t Y[] = {115};

// Minutos para bloque "Y" (Filas 11, 12, 13)
const uint8_t VEINTE_Y[] = {131, 130, 129, 128, 127, 126};
const uint8_t DIEZ_Y[] = {124, 123, 122, 121};
const uint8_t VEINTICINCO_Y[] = {132, 133, 134, 135, 136, 137, 138, 139, 140, 141, 142};
const uint8_t CINCO_Y[] = {138, 139, 140, 141, 142};
const uint8_t CUARTO_Y[] = {153, 152, 151, 150, 149, 148};
const uint8_t MEDIA[] = {147, 146, 145, 144, 143};

// Puntos de minutos individuales (índices 154 a 157)
const uint8_t MIN_LEDS[4] = { 154, 155, 156, 157 };

/* ========== Funciones Auxiliares ========== */

inline bool isWifiLed(uint8_t idx) {
  for (uint8_t i = 0; i < 4; i++) {
    if (WIFI_LEDS[i] == idx) return true;
  }
  return false;
}

void clearTarget() {
  fill_solid(targetLeds, NUM_LEDS, CRGB::Black);
}

void setW(const uint8_t *arr, uint8_t len, const char *name = nullptr) {
  for (uint8_t i = 0; i < len; i++) {
    uint8_t idx = arr[i];
    if (idx < NUM_LEDS && !isWifiLed(idx)) {
      targetLeds[idx] = WORD_COLOR;
    }
  }
  if (name) logW(name);
}

void setMinuteDotsTarget(uint8_t count) {
  for (uint8_t i = 0; i < 4; i++) {
    uint8_t idx = MIN_LEDS[i];
    if (idx < NUM_LEDS) {
      targetLeds[idx] = (i < count) ? WORD_COLOR : CRGB::Black;
    }
  }
}

/* ========== Lectura del Hardware RTC Grove DS1307 ========== */
DateTime getValidRtcDateTime() {
  DateTime now = rtc.now();

  // Verificación de rango BCD seguro (Hora 0-23, Minuto 0-59, Mes 1-12, Año 2024-2099)
  if (now.hour() > 23 || now.minute() > 59 || now.month() == 0 || now.month() > 12 || now.year() < 2024 || now.year() > 2099) {
    static unsigned long lastFixTime = 0;
    if (millis() - lastFixTime > 5000) {
      lastFixTime = millis();
#if DEBUG_SERIAL
      Serial.println(F("[ALERTA DS1307] Lectura BCD fuera de rango. Inicializando registros con hora de compilación..."));
#endif
      rtc.adjust(DateTime(F(__DATE__), F(__TIME__)));
      delay(30);
      now = rtc.now();
    }
  }
  return now;
}

/* ========== Diagnóstico Detallado en Puerto Serial ========== */
void printStartupDiagnostics() {
#if DEBUG_SERIAL
  Serial.println(F("\n=========================================================="));
  Serial.println(F("   WORDCLOCK - DIAGNOSTICO DE INICIALIZACION Y HARDWARE    "));
  Serial.println(F("   Placa: Seeed Studio XIAO ESP32-C6 + LED Driver Board  "));
  Serial.println(F("=========================================================="));

  // 1. Diagnóstico del Procesador ESP32-C6
  Serial.printf("[DIAGNOSTICO] Frecuencia CPU: %d MHz | Memoria Heap Libre: %d bytes\n",
                ESP.getCpuFreqMHz(), ESP.getFreeHeap());

  // 2. Escaneo del Bus I2C en la dirección 0x68 (DS1307)
  Wire.beginTransmission(0x68);
  byte i2cErr = Wire.endTransmission();

  if (i2cErr == 0) {
    Serial.println(F("[OK] Bus I2C (100 kHz): Módulo Grove DS1307 detectado en dirección 0x68."));
  } else {
    Serial.printf("[ERROR] Bus I2C: No respondió dirección 0x68 (Código I2C: %d)\n", i2cErr);
  }

  if (rtc.begin()) {
    Serial.println(F("[OK] Librería RTClib: Comunicación con Grove DS1307 correcta."));
    if (!rtc.isrunning()) {
      Serial.println(F("[ALERTA] Oscilador RTC: DS1307 inactivo (CH bit=1). Inicializando hora de compilación..."));
      rtc.adjust(DateTime(F(__DATE__), F(__TIME__)));
      delay(30);
    } else {
      Serial.println(F("[OK] Oscilador RTC: DS1307 activo y corriendo."));
    }

    DateTime now = getValidRtcDateTime();
    Serial.printf("[INFO] Hora leída del Grove DS1307: %02d:%02d:%02d  %02d/%02d/%04d\n",
                  now.hour(), now.minute(), now.second(),
                  now.day(), now.month(), now.year());
  } else {
    Serial.println(F("[ERROR] Librería RTClib: Falló rtc.begin() para DS1307. Verifique VCC 5V y conector Grove."));
  }

  // 3. Diagnóstico de FastLED
  Serial.printf("[OK] FastLED: Inicializado en Pin D0 (GPIO %d) para %d LEDs.\n", DATA_PIN, NUM_LEDS);

  // 4. Diagnóstico del LED Integrado
  Serial.printf("[OK] LED Integrado XIAO: Configurado en GPIO %d (Parpadeo durante WiFi AP).\n", LED_PIN_BUILTIN);

  // 5. Diagnóstico de Preferencias Guardadas
  Serial.printf("[OK] Ajustes NVS: Brillo Día=%d%%, Brillo Noche=%d%% (%02dh-%02dh), Color RGB=(%d,%d,%d)\n",
                dayBrightPercent, nightBrightPercent, nightStartHour, nightEndHour,
                WORD_COLOR.r, WORD_COLOR.g, WORD_COLOR.b);

  // 6. Diagnóstico del Punto de Acceso WiFi
  Serial.print(F("[OK] Captive Portal WiFi AP: SSID 'WORDCLOCK-SETUP' | IP: "));
  Serial.println(WiFi.softAPIP());
  Serial.println(F("==========================================================\n"));
#endif
}

void printDebugStatus(int hourVal, int minuteVal) {
#if DEBUG_SERIAL
  DateTime now = getValidRtcDateTime();
  Serial.println(F("---------------------------------"));
  Serial.printf("Grove DS1307 RTC ahora: %02d:%02d:%02d  %02d/%02d/%04d\n",
                now.hour(), now.minute(), now.second(),
                now.day(), now.month(), now.year());
  Serial.printf("Hora solicitada para render: %02d:%02d\n", hourVal, minuteVal);
  Serial.print(F("Oración desplegada: "));
  Serial.println(debugWords);

  Serial.print(F("LEDs activos (excluyendo WIFI): "));
  bool first = true;
  for (int i = 0; i < NUM_LEDS; i++) {
    if (targetLeds[i].r != 0 || targetLeds[i].g != 0 || targetLeds[i].b != 0) {
      if (!first) Serial.print(", ");
      Serial.print(i);
      first = false;
    }
  }
  Serial.println();
  Serial.println(F("---------------------------------"));
#endif
}

/* ========== Transición Suave No Bloqueante entre Palabras ========== */
void startWordTransition(int hourVal, int minuteVal) {
  // Almacenar el estado actual de cada LED de la hora (excluyendo WIFI)
  for (int i = 0; i < NUM_LEDS; i++) {
    previousLeds[i] = isWifiLed(i) ? CRGB::Black : leds[i];
  }
  buildTimeTarget(hourVal, minuteVal);
  transitionStartTime = millis();
  inTransition = true;
}

/* ========== Función Auxiliar de Mapeo de Horas ========== */
void hour(uint8_t h) {
  switch (h) {
    case 1: setW(UNA, 3, "UNA"); break;
    case 2: setW(DOS, 3, "DOS"); break;
    case 3: setW(TRES, 4, "TRES"); break;
    case 4: setW(CUATRO, 6, "CUATRO"); break;
    case 5: setW(CINCO_H, 5, "CINCO"); break;
    case 6: setW(SEIS, 4, "SEIS"); break;
    case 7: setW(SIETE, 5, "SIETE"); break;
    case 8: setW(OCHO, 4, "OCHO"); break;
    case 9: setW(NUEVE, 5, "NUEVE"); break;
    case 10: setW(DIEZ_H, 4, "DIEZ"); break;
    case 11: setW(ONCE, 4, "ONCE"); break;
    case 12: setW(DOCE, 4, "DOCE"); break;
  }
}

bool isNightHour(uint8_t hour) {
  if (nightStartHour == nightEndHour) return false;
  if (nightStartHour < nightEndHour) {
    return (hour >= nightStartHour && hour < nightEndHour);
  } else {
    return (hour >= nightStartHour || hour < nightEndHour);
  }
}

/* ========== Generador de Mapeo de Hora a LEDs ========== */
void buildTimeTarget(int hourVal, int minuteVal) {
  debugWords = "";

  // Ajuste automático de brillo Día/Noche con Corrección Gamma
  uint8_t effectivePercent = isNightHour(hourVal) ? nightBrightPercent : dayBrightPercent;
  uint8_t brightnessVal = perceptualBrightness(effectivePercent);
  FastLED.setBrightness(brightnessVal);

  clearTarget();

  uint8_t rounded = (minuteVal / 5) * 5;
  uint8_t extra = minuteVal % 5;

  uint8_t h = hourVal % 12;
  if (h == 0) h = 12;

  uint8_t nextHour = (h % 12) + 1;

  if (rounded >= 35) {
    // --- BLOQUE DE MINUTOS "PARA" (35 a 59) ---
    setW(SON, 3, "SON");
    switch (rounded) {
      case 35:
        setW(VEINTICINCO_PARA, 11, "VEINTICINCO");
        setW(PARA, 4, "PARA");
        break;
      case 40:
        setW(VEINTE_PARA, 6, "VEINTE");
        setW(PARA, 4, "PARA");
        break;
      case 45:
        setW(CUARTO_PARA, 6, "CUARTO");
        setW(PARA, 4, "PARA");
        break;
      case 50:
        setW(DIEZ_PARA, 4, "DIEZ");
        setW(PARA, 4, "PARA");
        break;
      case 55:
        setW(CINCO_PARA, 5, "CINCO");
        setW(PARA, 4, "PARA");
        break;
    }

    // Artículo antes de la hora: "LA" si la siguiente hora es 1, "LAS" para las demás
    if (nextHour == 1) {
      setW(LA_PARA, 2, "LA");
    } else {
      setW(LAS_PARA, 3, "LAS");
    }

    // Siguiente hora
    if (nextHour == 1) {
      setW(UNA_PARA, 3, "UNA");
    } else {
      hour(nextHour);
    }

  } else {
    // --- BLOQUE DE HORA EN PUNTO O CONJUNCIÓN "Y" (0 a 34) ---
    // Verbo + Artículo: "ES LA" si la hora es 1, "SON LAS" para las demás
    if (h == 1) {
      setW(ES, 2, "ES");
      setW(LA, 2, "LA");
    } else {
      setW(SON, 3, "SON");
      setW(LAS, 3, "LAS");
    }

    // Hora actual
    hour(h);

    // Adición de minutos
    switch (rounded) {
      case 5:
        setW(Y, 1, "Y");
        setW(CINCO_Y, 5, "CINCO");
        break;
      case 10:
        setW(Y, 1, "Y");
        setW(DIEZ_Y, 4, "DIEZ");
        break;
      case 15:
        setW(Y, 1, "Y");
        setW(CUARTO_Y, 6, "CUARTO");
        break;
      case 20:
        setW(Y, 1, "Y");
        setW(VEINTE_Y, 6, "VEINTE");
        break;
      case 25:
        setW(Y, 1, "Y");
        setW(VEINTICINCO_Y, 11, "VEINTICINCO");
        break;
      case 30:
        setW(Y, 1, "Y");
        setW(MEDIA, 5, "MEDIA");
        break;
    }
  }

  uint8_t dotsToLight = (minuteVal >= 35) ? (4 - extra) : extra;
  setMinuteDotsTarget(dotsToLight);
  printDebugStatus(hourVal, minuteVal);
}

/* ========== Servidor Web del Portal Cautivo WiFi ========== */

String makePageHtml() {
  char colorHex[8];
  sprintf(colorHex, "#%02X%02X%02X", WORD_COLOR.r, WORD_COLOR.g, WORD_COLOR.b);

  DateTime now = getValidRtcDateTime();
  int curY = now.year();
  int curM = now.month();
  int curD = now.day();
  int curH = now.hour();
  int curMin = now.minute();

  char rtcBuf[64];
  sprintf(rtcBuf, "%02d/%02d/%04d %02d:%02d:%02d",
          curD, curM, curY, curH, curMin, now.second());

  String html = R"rawliteral(
<!DOCTYPE html>
<html lang="es">
<head>
<meta charset="UTF-8">
<meta name="viewport" content="width=device-width, initial-scale=1.0">
<title>Word Clock Config</title>
<style>
@import url('https://fonts.googleapis.com/css2?family=Outfit:wght@300;400;600;700&display=swap');
body {
  margin: 0;
  background: #0d0f12;
  color: #f0f3f6;
  font-family: 'Outfit', sans-serif;
  display: flex;
  justify-content: center;
  align-items: center;
  min-height: 100vh;
  padding: 15px;
  box-sizing: border-box;
}
.container {
  max-width: 400px;
  width: 100%;
  background: rgba(22, 26, 33, 0.85);
  border: 1px solid rgba(255, 255, 255, 0.08);
  backdrop-filter: blur(16px);
  border-radius: 20px;
  padding: 20px;
  box-shadow: 0 20px 40px rgba(0, 0, 0, 0.5);
  box-sizing: border-box;
}
h1 {
  text-align: center;
  font-size: 1.5rem;
  font-weight: 700;
  margin-top: 5px;
  margin-bottom: 4px;
  background: linear-gradient(135deg, #f0f3f6 0%, #8b949e 100%);
  -webkit-background-clip: text;
  -webkit-text-fill-color: transparent;
}
.subtitle {
  text-align: center;
  font-size: 0.78rem;
  color: #6e7681;
  margin-bottom: 12px;
}
.status-banner {
  background: rgba(16, 185, 129, 0.15);
  border: 1px solid rgba(16, 185, 129, 0.3);
  padding: 8px 12px;
  border-radius: 10px;
  text-align: center;
  margin-bottom: 15px;
  color: #34d399;
  font-size: 0.8rem;
  font-family: monospace;
  font-weight: bold;
}
.card {
  background: rgba(255, 255, 255, 0.03);
  border: 1px solid rgba(255, 255, 255, 0.05);
  padding: 12px 14px;
  border-radius: 12px;
  margin-bottom: 12px;
}
label {
  font-size: 0.85rem;
  font-weight: 600;
  display: flex;
  justify-content: space-between;
  align-items: center;
  margin-bottom: 6px;
  color: #8b949e;
}
.val-display {
  color: #38bdf8;
  font-family: monospace;
  font-weight: bold;
}
input[type=color] {
  width: 100%;
  height: 36px;
  border: none;
  background: none;
  cursor: pointer;
  padding: 0;
}
.swatches {
  display: flex;
  gap: 8px;
  margin-top: 8px;
  justify-content: space-between;
}
.swatch {
  width: 22px;
  height: 22px;
  border-radius: 50%;
  cursor: pointer;
  border: 2px solid transparent;
  transition: transform 0.2s, border-color 0.2s;
}
.swatch:hover { transform: scale(1.15); }
.swatch.active { border-color: #ffffff; }

input[type=range] {
  width: 100%;
  height: 4px;
  background: #2a313d;
  outline: none;
  border-radius: 2px;
  -webkit-appearance: none;
  margin: 8px 0 4px 0;
}
input[type=range]::-webkit-slider-thumb {
  -webkit-appearance: none;
  width: 16px;
  height: 16px;
  border-radius: 50%;
  background: #38bdf8;
  cursor: pointer;
}
.row {
  display: flex;
  gap: 12px;
}
.small-input {
  width: 100%;
  height: 34px;
  background: #1c212b;
  border: 1px solid rgba(255,255,255,0.08);
  border-radius: 6px;
  color: #fff;
  font-size: 0.9rem;
  text-align: center;
}
.small-input:focus {
  outline: none;
  border-color: #38bdf8;
}
.rtc-box {
  text-align: center;
  background: rgba(0, 0, 0, 0.3);
  padding: 8px;
  border-radius: 6px;
  font-family: monospace;
  font-size: 0.85rem;
  color: #38bdf8;
  margin: 6px 0 10px 0;
  border: 1px solid rgba(56, 189, 248, 0.15);
}
.btn-save {
  width: 100%;
  background: #38bdf8;
  color: #0f1115;
  border: none;
  padding: 11px;
  border-radius: 10px;
  font-size: 0.9rem;
  font-weight: bold;
  cursor: pointer;
  transition: background 0.2s;
  margin-top: 5px;
}
.btn-save:hover { background: #7dd3fc; }

.btn-sync {
  width: 100%;
  background: #2a313d;
  color: #f0f3f6;
  border: none;
  padding: 8px;
  border-radius: 8px;
  font-size: 0.8rem;
  font-weight: bold;
  cursor: pointer;
  transition: background 0.2s;
}
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
void loop() {
  dnsServer.processNextRequest();
  server.handleClient();

  // Control del parpadeo del LED Integrado del XIAO durante WiFi activo
  handleBuiltinLedStatus();

  if (apActive) {
    int stations = WiFi.softAPgetStationNum();
    if (stations > 0) {
      clientConnected = true;
    }

    // Tiempo límite del Punto de Acceso: apagar tras 60 segundos si ningún usuario se conecta
    if (!clientConnected && (millis() - apStartTime > 60000UL)) {
      dnsServer.stop();
      WiFi.softAPdisconnect(true);
      apActive = false;
      clientConnected = false;
#if DEBUG_SERIAL
      Serial.println(F("[WIFI] AP apagado por tiempo límite (60s sin clientes)."));
#endif
    }

    // Apagado del Punto de Acceso: cliente desconectado
    if (clientConnected && (WiFi.softAPgetStationNum() == 0) && (millis() - apStartTime > 500)) {
      dnsServer.stop();
      WiFi.softAPdisconnect(true);
      apActive = false;
      clientConnected = false;
#if DEBUG_SERIAL
      Serial.println(F("[WIFI] AP apagado: Cliente desconectado."));
#endif
    }
  }

  // Bucle de tiempo (comprobación no bloqueante del RTC cada 250 ms)
  static unsigned long lastRtcCheck = 0;
  if (millis() - lastRtcCheck >= 250) {
    lastRtcCheck = millis();
    DateTime now = getValidRtcDateTime();
    if (now.minute() != lastMinute) {
      lastMinute = now.minute();
      startWordTransition(now.hour(), now.minute());
    }
  }

  // Renderizado continuo por capas a ~50 FPS
  updateLedsNonBlocking();
  delay(20);
}

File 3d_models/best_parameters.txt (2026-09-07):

Quality - Line width - Top Surface: 0.36
Quality - Advanced - Top surface flow ratio: 1.01
Strength - top/bottom shells - Internal Solid infill pattern : Monotonic Line
Speed - Other Layers Speed - Top Surface: 70 mm/s


2.8.2.61

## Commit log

2026-09-07 Initial commit: Reorganize WordClock project structure (simulator, arduino, 3D models, backups, docs)
    [best_parameters.txt, wordclock_back_lid.3mf, wordclock_back_lid.scad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]
2026-09-07 chore: add dual LICENSE and clean legacy backups from main
    [wordclock_back_lid.scad, wordclock_back_lid.stl, wordclock_electronics_mount.scad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]
2026-09-07 docs: add hardware wiring diagram, pinout table, and power recommendations
2026-09-07 docs: correct hardware wiring diagram and specifications for Seeed LED Driver Board (12V input, on-board Grove and LED output)
2026-09-07 docs: add official Seeed wiki links and BOM items (USB-C panel port and 12V 2A adapter)
2026-09-07 docs: add physical internal assembly photo to hardware section
2026-09-07 docs: add 3D CAD exploded assembly render to 3D printing documentation
2026-09-07 feat(3d): add complete preconfigured Bambu Studio project file (wordclock.3mf)
    [wordclock.3mf]
2026-09-10 feat(leds): add gamma 2.2 correction, S-curve crossfade, and Apple breathing curve
    [wordclock.ino]
2026-09-10 docs: reorder usage guide placing WiFi setup after 3D printing and assembly
2026-09-10 feat(leds): implement non-blocking layered rendering and zero-origin breathing curve
